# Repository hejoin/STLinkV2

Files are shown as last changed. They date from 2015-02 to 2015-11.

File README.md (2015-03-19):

# STLinkV2
Клон STLink/V2
Задумывается как самодельная и доступная альтернатива продаваемому программатору от STMicroelectronics. Является выдержкой и компиляцией нескольких статей и схем найденных в интернете. Предполагается реализация в минимально возможном форм-факторе.

Основные функции:
- программирование и отладка STM32
- программирование и отладка STM8

Интерфейсы программирования:
- SWD
- JTAG
- SWIM

Устройство проверенно:
- обновление прошивки по средством ST-Link утилиты - OK
- программирование и отладка STM32 - OK
- программирование и отладка STM8 - OK

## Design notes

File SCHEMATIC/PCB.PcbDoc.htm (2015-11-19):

Reporting Options

# File in Previous Format

Date | : | 19.11.2015
Time | : | 21:19:57
Filename | : | C:\Users\Денис\OneDrive\1. Проекты\STLinkV2\SCHEMATIC\PCB.PcbDoc

Version | Warning

This file was generated by an earlier version of the software

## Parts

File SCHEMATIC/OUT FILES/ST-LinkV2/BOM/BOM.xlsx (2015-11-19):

Designator | Value | Voltage | Manufacturer Part Number | Package | Description | Footprint_Description | Quantity
C1, C2, C3, C6, C8, C9, C10 | 0u1 |  |  | SMD 0603 | Capacitor 0u1 | Chip Capacitorr EIA 0603. METRIC 1608, 2-Leads, Body 1,6x0,8mm, IPC Medium Density | 7
C4 | 22u | 10V |  | CAPMP3216X180N | Polarized capacitor 22u*10V | Capacitor, polarized, Molded Body, EIA 535BAAC size A; 3.20mm L X 1.60mm W X 1.80mm H | 1
C5, C7 | 22p |  |  | SMD 0603 | Capacitor 22p | Chip Capacitorr EIA 0603. METRIC 1608, 2-Leads, Body 1,6x0,8mm, IPC Medium Density | 2
D1, D2 |  |  |  | SOD-123 | Diode MBR0520 |  | 2
LD1 |  |  |  | 805 | Diode Led Green |  | 1
LD2 |  |  | FYLS-1210 EGW | 2.0X1.25X1.1 |  | Generic 1210 Bi-Colour SMT LED | 1
P1 |  |  |  |  | Connector Header 4 | Connector; Header; 4 Position | 1
P2 |  |  | 47346-0001 |  | Micro-USB B Receptacle with Flange, Bottom Mount, Surface Mount, Lead-Free | Micro-USB B Receptacle with Flange, Bottom Mount, Surface Mount, Lead-Free | 1
P3 |  |  |  |  | Connector IDC-14MS-EDGE |  | 1
R1 | 10R |  |  | SMD 0603 | Resistor 10R SMD 0603 | Chip Resistor EIA 0603. METRIC 1608, 2-Leads, Body 1,6x0,8mm, IPC Medium Density | 1
R2, R3, R4, R5, R6, R7, R8, R9, R10, R11 | 22R |  |  | SMD 0603 | Resistor 22R SMD 0603 | Chip Resistor EIA 0603. METRIC 1608, 2-Leads, Body 1,6x0,8mm, IPC Medium Density | 10
R12 | 1.5k |  |  | SMD 0603 | Resistor 1.5k SMD 0603 | Chip Resistor EIA 0603. METRIC 1608, 2-Leads, Body 1,6x0,8mm, IPC Medium Density | 1
R13, R14 | 4.7k |  |  | SMD 0603 | Resistor 4.7k SMD 0603 | Chip Resistor EIA 0603. METRIC 1608, 2-Leads, Body 1,6x0,8mm, IPC Medium Density | 2
R15, R17, R18, R19 | 680R |  |  | SMD 0603 | Resistor 680R SMD 0603 | Chip Resistor EIA 0603. METRIC 1608, 2-Leads, Body 1,6x0,8mm, IPC Medium Density | 4
R16, R21, R22 | 220R |  |  | SMD 0603 | Resistor 220R SMD 0603 | Chip Resistor EIA 0603. METRIC 1608, 2-Leads, Body 1,6x0,8mm, IPC Medium Density | 3
R20 | 100k |  |  | SMD 0603 | Resistor 100k SMD 0603 | Chip Resistor EIA 0603. METRIC 1608, 2-Leads, Body 1,6x0,8mm, IPC Medium Density | 1
U1, U2 |  |  | ESDA5V3SC5 | SOT23-5 | Quad Zenner array for ESD protection, 5.3V |  | 2
U3 |  |  | LM1117MPX-3.3/NOPB | SOT223 | Voltage Regulators LM1117-3.3 | SOT-223/SC-73; 4 Leads; Body 6.7 x 7.3 mm, inc. leads (LxW max) | 1
U4 |  |  | STM32F103C8T6 | LQFP48 | Microcontroller STM32F103C8T6 |  | 1
Y1 | 8MHz |  |  | HC-49H | Crystal 8MHz |  | 1

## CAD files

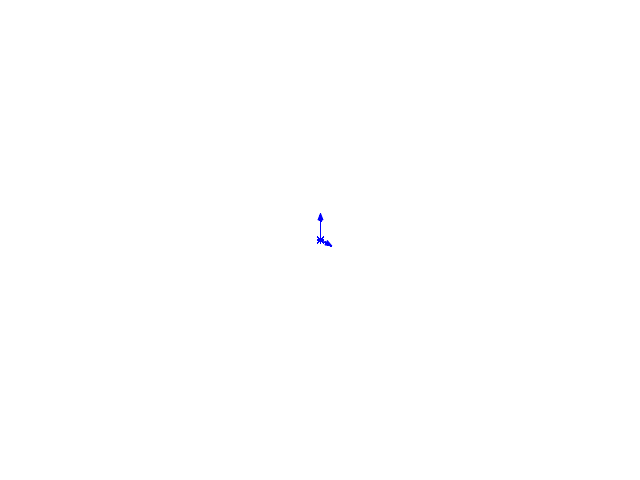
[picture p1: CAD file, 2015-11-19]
3DMODEL/Исходники/sod_123.sldasm
sod_123_body
sod_123_pin x 2

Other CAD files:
3DMODEL/Исходники/R10.sldasm
3DMODEL/Исходники/R7.sldasm
3DMODEL/Исходники/R15.sldasm
3DMODEL/Исходники/R14.sldasm
3DMODEL/Исходники/R8.sldasm
3DMODEL/Исходники/C2.sldasm
3DMODEL/Исходники/R18.sldasm
3DMODEL/Исходники/R9.sldasm
3DMODEL/Исходники/R20.sldasm
3DMODEL/Исходники/C3.sldasm
3DMODEL/Исходники/LD1.sldasm
3DMODEL/Исходники/R4.sldasm
3DMODEL/Исходники/U3.sldasm
3DMODEL/Исходники/R2.sldasm
3DMODEL/Исходники/C8.sldasm
3DMODEL/Исходники/R16.sldasm
3DMODEL/Исходники/Y1.sldasm
3DMODEL/Для печати/bottom.STL
3DMODEL/Для печати/top.STL
3DMODEL/Исходники/1191387192.sldasm
3DMODEL/Исходники/1191395352.sldasm
3DMODEL/Исходники/1191395488.sldasm
3DMODEL/Исходники/1191395624.sldasm
3DMODEL/Исходники/474910001.sldasm
3DMODEL/Исходники/Board.sldprt
3DMODEL/Исходники/C0603C.sldprt
3DMODEL/Исходники/C0603R.sldprt
3DMODEL/Исходники/C1.sldasm
3DMODEL/Исходники/C10.sldasm
3DMODEL/Исходники/C4.sldasm
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

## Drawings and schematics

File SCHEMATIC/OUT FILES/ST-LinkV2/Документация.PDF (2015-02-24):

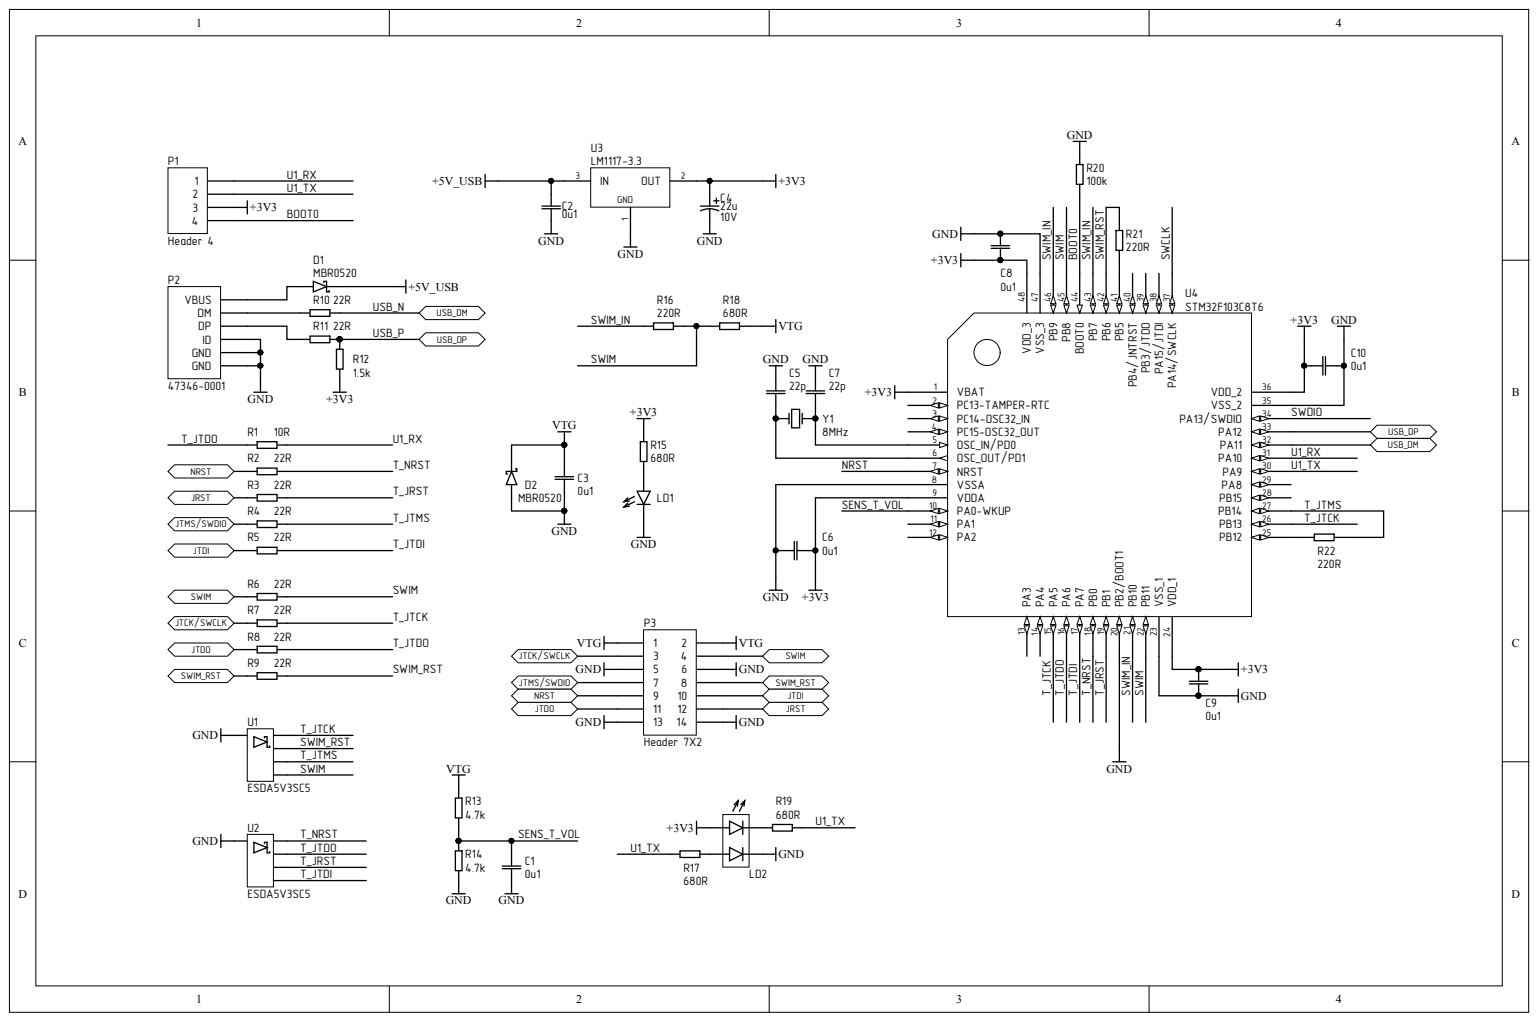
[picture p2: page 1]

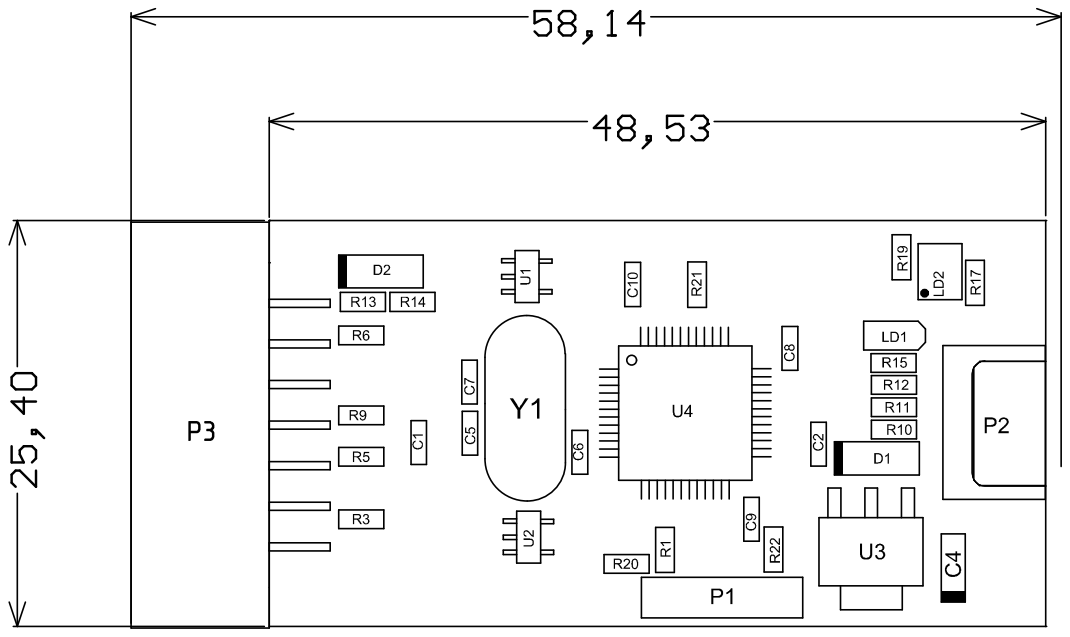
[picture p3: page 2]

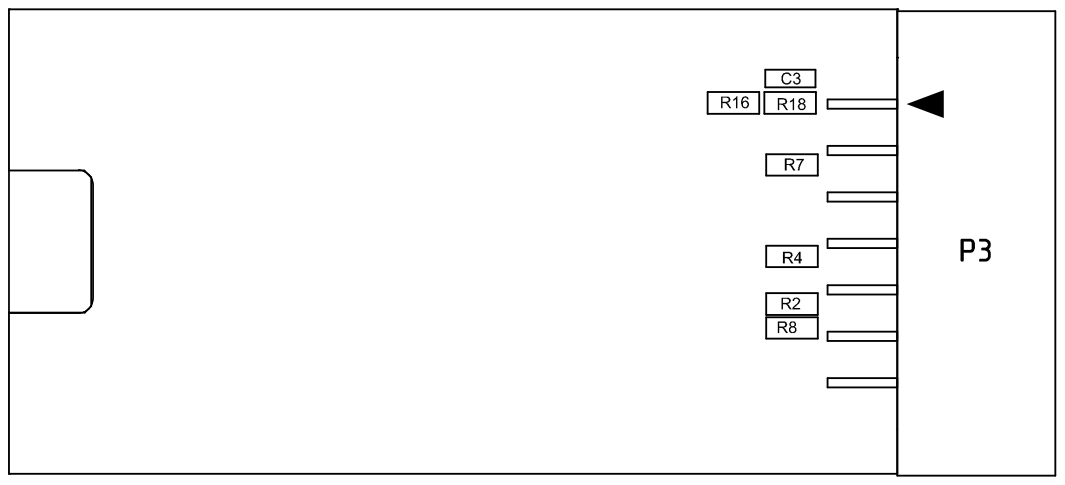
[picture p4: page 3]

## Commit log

2015-02-18 Начало положено. + Принципиальная схема, есть ещё ошибки, нужно исправить + гитигнор
    [ST-LinkV2.PrjPCB, St-LinkV2.SchDoc]
2015-02-19 Начал делать печатку
    [PCB.GBL, PCB.GBO, PCB.GBP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]
2015-02-20 изменил разъём.
    [St-LinkV2.SchDoc]
2015-02-24 Исправил некоторые косяки, в основном в библиотеках.
    [PCB.PcbDoc, ST-LinkV2.PrjPCB, St-LinkV2.SchDoc]
2015-02-24 расставил элементы на плате, нужно развести
    [PCB.PcbDoc]
2015-02-24 До конца развёл плату, не много упростил схему, сгенерировал документацию для производства, добавил папки с прошивкой и загрузчиком.
    [PCB.GBL, PCB.GBO, PCB.GBP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]
2015-02-25 Сгенерирована документация для производства и сделан скрипт для переименовывания герберов.
    [BOM.xlsx, ST-LinkV2.PrjPCB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]
2015-02-25 Нашел в интернете бутлоадер от ST-Link, теперь можно не заморачиваться с поиском прошивки, при первом включении и запуске обновления можно будет выбрать необходимую версию
2015-11-19 3d модели корпуса и платы
    [1191387192.sldasm, 1191395352.sldasm, 1191395488.sldasm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]
